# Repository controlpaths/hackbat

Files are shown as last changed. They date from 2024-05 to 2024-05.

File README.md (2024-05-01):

# Hackbat

HackBat is an open-source device designed for hackers and makers to experiment with different pen-testing techniques. The device is based on the Raspberry Pi RP2040 microcontroller and has an RF transceiver, NFC, WIFI, OLED display...

## RP2040

The Raspberry Pi [RP2040](https://www.raspberrypi.com/products/rp2040/specifications/) is the brain of the HackBat. The main features of this MCU are:

- Dual-core Arm Cortex-M0+ processor, flexible clock running up to 133 MHz 264kB on-chip SRAM
- 2 × UART 
- 2 × SPI controllers
- 2 × I2C controllers
- 16 × PWM channels
- 1 × USB 1.1 controller and PHY, with host and device support
- 8 × Programmable I/O (PIO) state machines for custom peripheral support
- Operating temperature -40°C to +85°C
- Drag-and-drop programming using mass storage over USB
- Low-power sleep and dormant modes
- Temperature sensor
- Accelerated integer and floating-point libraries on-chip

The RP2040 can be programmed using Arduino IDE, Python or C++.

## Display

The OLED display used in the HackBat is a 128x64 pixels, with the driver SH110X. The device also allows OLED with SSD1306, but notice that the VCC and GND pins are reversed, so you need to change the 0 ohm resistors of those pins.

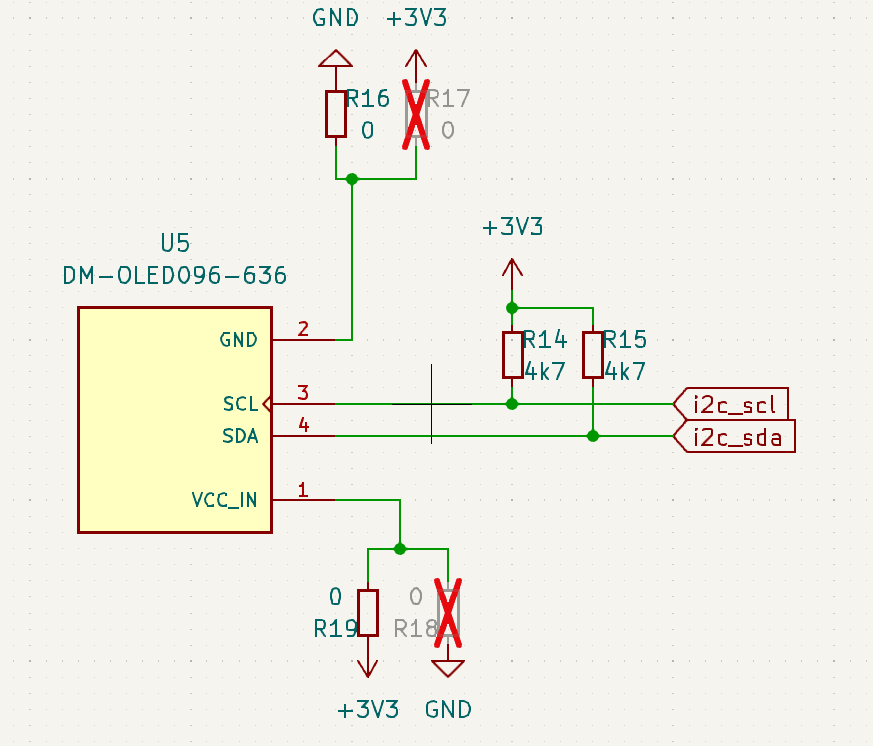
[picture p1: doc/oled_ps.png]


## RF

The Hackbat features a [CC1101](https://www.ti.com/product/CC1101) from Texas instruments. CC1101 is a low-cost sub-1 GHz transceiver designed for very low-power wireless applications. The circuit is mainly intended for the ISM (Industrial, cientific and Medical) and SRD (Short Range Device) frequency bands at 315, 433, 868, and 915 MHz, but can easily be programmed for operation at other frequencies in the 300-348 MHz, 387-464 MHz and 779-928 MHz bands

## WIFI

The hackBat features an ESP8266 module, the ESP-12F. This module allow either the HackBat to connect a WIFI network, or generate an access point to allow connections.

The ESP-12F modules can be programmed using the Arduino IDE and the UART conenction. In the HackBat, the ESP-12F is programmed through the RP2040 by using it as USB-UART bridge.

## NFC

HackBat has NFC communication at 13.56MHz. The IC in charge of this peripheral is the [PN532].

PN532 is a highly integrated transceiver module for contactless communication at 13.56 MHz based on the 80C51 microcontroller core supporting different card and reader/writer operating modes.

HackBat uses [this](https://es.aliexpress.com/item/1005006005040320.html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) integrated module with the PN532.

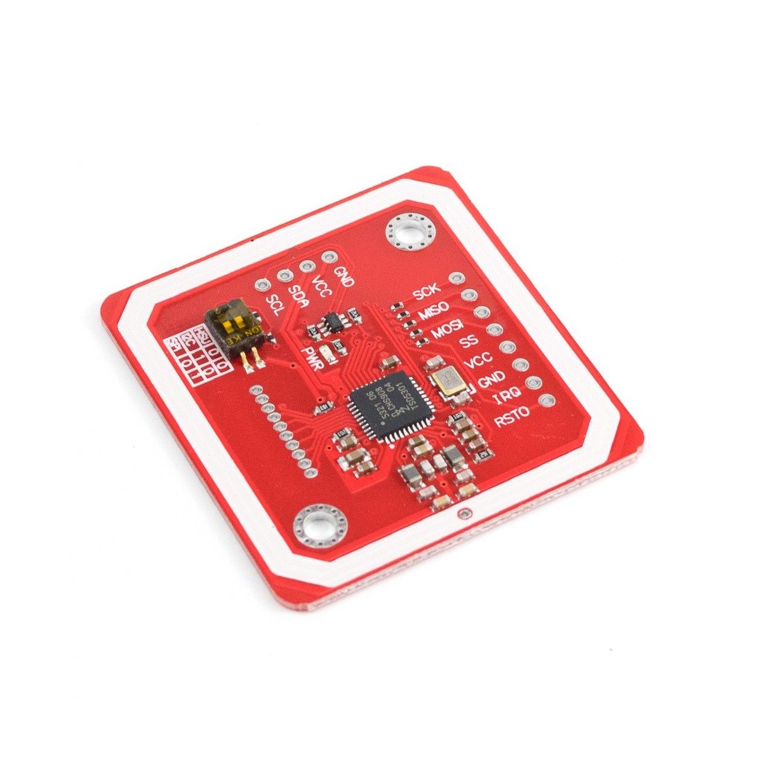
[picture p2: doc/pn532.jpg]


The communication with the RP2040 is I2C.

## Keyboard emulation

Since the RP2040 has USB host/Device, the HackBat can be used as a keyboard emulator using the Arduinoi `keyboard.h` library.

## Get Yours

The HackBat is open-source, so you can use the output files to manufacture your own in [JLCPCB](https://jlcpcb.com/?from=controlpath). You just need to compress the `output_files` directory, and upload it to [JLCPCB](https://jlcpcb.com/?from=controlpath). 

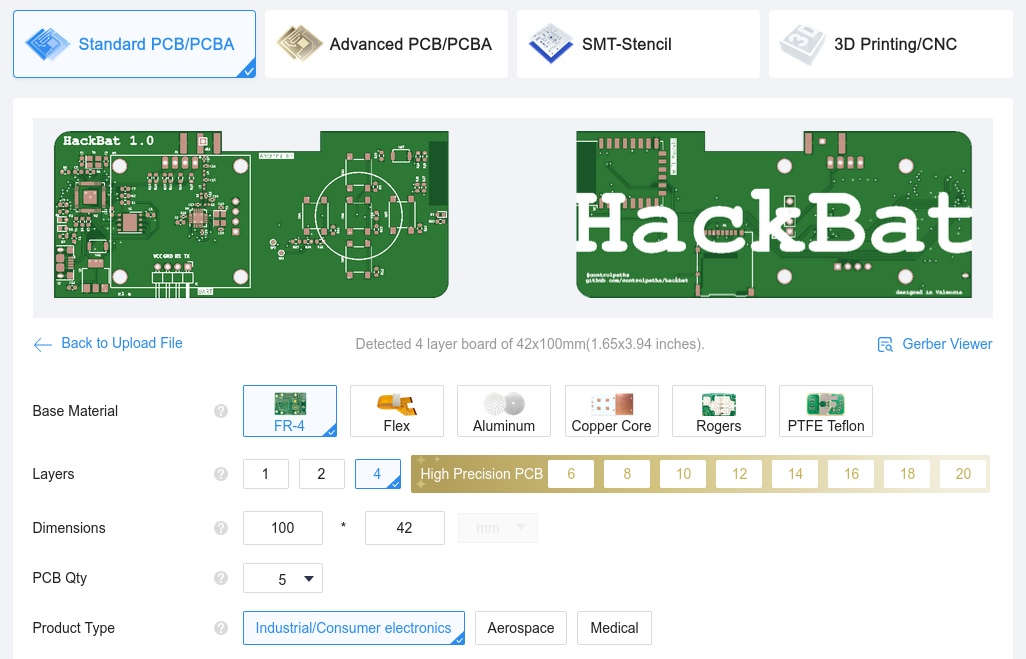
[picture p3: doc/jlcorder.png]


Remember to change the Surface Finish to **LeadFree HASL** to make your board ROHS compliant.

Then you have to add the PCB Assembly service and upload the [centroid](./kicad/hackbat/production_files/hackbat-all-pos.csv) file, and the [BOM](./kicad/hackbat/production_files/bom.csv). 

In a few days, you will receive your board at home.

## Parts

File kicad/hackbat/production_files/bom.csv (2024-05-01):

# | Reference | Qty | Value | Footprint | DNP | JLCPCB Part #
1 | AE1 | 1 | Antenna | TestPoint:TestPoint_THTPad_1.5x1.5mm_Drill0.7mm
2 | C1, C5, C7, C11 | 4 | 1u | Capacitor_SMD:C_0603_1608Metric
3 | C2, C3 | 2 | 15p | Capacitor_SMD:C_0603_1608Metric
4 | C4, C6, C8, C9, C10, C12 | 6 | 100n | Capacitor_SMD:C_0603_1608Metric
5 | C13, C21 | 2 | 3.9p | Capacitor_SMD:C_0402_1005Metric
6 | C14, C17 | 2 | 220p | Capacitor_SMD:C_0402_1005Metric
7 | C15 | 1 | 8.2p | Capacitor_SMD:C_0402_1005Metric
8 | C16 | 1 | 5.6p | Capacitor_SMD:C_0402_1005Metric
9 | C18 | 1 | 100n | Capacitor_SMD:C_0402_1005Metric
10 | C19, C20 | 2 | 27p | Capacitor_SMD:C_0402_1005Metric
11 | D1, D2, D3 | 3 | LED | LED_SMD:LED_0603_1608Metric |  | C19189746
13 | J2 | 1 | USB_B_Micro | Connector_USB:USB_Micro-B_Amphenol_10118193-0001LF_Horizontal |  | C132562
15 | J4 | 1 | Micro_SD_Card_Det_Hirose_DM3AT | Connector_Card:microSD_HC_Hirose_DM3AT-SF-PEJM5 |  | C114218
16 | J5 | 1 | Conn_01x04_Pin | Connector_PinHeader_2.54mm:PinHeader_1x04_P2.54mm_Horizontal
17 | L1, L2 | 2 | 27nH | Inductor_SMD:L_0402_1005Metric
18 | L3 | 1 | 22n | Inductor_SMD:L_0402_1005Metric
19 | L4 | 1 | 27n | Inductor_SMD:L_0402_1005Metric
20 | R1, R6 | 2 | 1k | Resistor_SMD:R_0603_1608Metric
21 | R2, R5 | 2 | 10k | Resistor_SMD:R_0603_1608Metric
22 | R3, R4 | 2 | 27 | Resistor_SMD:R_0603_1608Metric
23 | R7, R8, R9, R10, R11, R12, R13, R14, R15, R20, R22, R27, R28, R29 | 14 | 4k7 | Resistor_SMD:R_0603_1608Metric
24 | R16, R19, R23, R24, R25, R26 | 6 | 0 | Resistor_SMD:R_0603_1608Metric
26 | R21 | 1 | 56k | Resistor_SMD:R_0402_1005Metric
27 | SW1, SW7 | 2 | SW_Push | Button_Switch_SMD:SW_Push_SPST_NO_Alps_SKRK |  | C115357
28 | SW2, SW3, SW4, SW5, SW6 | 5 | SW_Push | Button_Switch_SMD:SW_Push_1P1T_NO_6x6mm_H9.5mm |  | C455109
30 | U1 | 1 | W25Q32JVZP | Package_SON:WSON-8-1EP_6x5mm_P1.27mm_EP3.4x4.3mm |  | C2940197
31 | U2 | 1 | RP2040 | Package_DFN_QFN:QFN-56-1EP_7x7mm_P0.4mm_EP3.2x3.2mm |  | C2040
32 | U3 | 1 | AMS1117-3.3 | Package_TO_SOT_SMD:SOT-223-3_TabPin2
33 | U4 | 1 | ESP-12F | RF_Module:ESP-12E |  | C784365
35 | U6 | 1 | CC1101 | Package_DFN_QFN:QFN-20-1EP_4x4mm_P0.5mm_EP2.6x2.6mm_ThermalVias |  | C29953
36 | Y1 | 1 | 12MHz | Crystal:Crystal_SMD_3225-4Pin_3.2x2.5mm |  | C524716
37 | Y2 | 1 | 27MHz | Crystal:Crystal_SMD_3225-4Pin_3.2x2.5mm |  | C254353

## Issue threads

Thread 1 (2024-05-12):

More info?

RonRN18, 2024-05-12:
I saw a blurb about this project but having difficulty finding any more information about it. From this Github, I see how the board can be built but as of yet, I have not seen any software to use on the hardware. Is more information forthcoming, such as instructions for programming and pointers on what can be accomplished with it?

rdfry, 2024-05-14:
I am also interested in programming this.

controlpaths, 2024-05-14:
Hi, this project is a HW platform. The board can be programmed using the Arduino IDE. All the peripherals except the RF have an Arduino library available so you can use it. For the RF IC, you need to modify the library from LSatan (SMARTRC-CC1101-Driver-Lib), or download the library from the repository of Joel Serna Moreno, who has a fork of the library modified for the RP2040.

Thanks!

Closed 2024-05-16.

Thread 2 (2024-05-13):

Layout issue?

DarthMuppet54, 2024-05-13:
This is excellent, many thanks for your efforts here.

I raised an order with PCBWAY for some of these to be built, and they have reported this to me:

> After checking your file, we found that there is via on pad in picture showing, may I know whether we should fill with resin or not
> 1. Fill with resin, the cost of pcb will increase and it will be good for assembly
> 2.Without resin, when you solder SMD components on pad, then paster will be easy leak out from pad

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

 Can you advise please?

Thanks

controlpaths, 2024-05-14:
Hi, some PCB manufacturers ask you about vias on pads because it could be a mistake, but not in this case.

Closed 2024-05-16.

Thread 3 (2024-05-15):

Bom file error

ygaspoz, 2024-05-15:
Hi, when uploading the files for the parts JLCPCB gives me the following error:
Error

The below parts won't be assembled due to data missing.
U5,J1,R18,R17 designators don't exist in the BOM file.
AE1 designator don't exist in the CPL file.

What is the fix?

fabinhojcr, 2024-05-15:
Upload the hackbat.zip file and you will be successful.

ygaspoz, 2024-05-15:
> Upload the hackbat.zip file and you will be successful.

I tried doing that, but when it prompts me to upload that BOM and CPL files I still get the same error.

TenThousand1, 2024-05-15:
I am also getting the exact same error message.

shayfer, 2024-05-15:
Same error message as well. It does make sense though since the hackbat-all-pos.csv references those items and they are not in the bom.csv file and vice versa for the AE1.

ygaspoz, 2024-05-16:
OK so i am correct in assuming that the display, antenna and NFC module need to be bought separately?

controlpaths, 2024-05-16:
That is correct. For the antenna, you can solder the antena or an SMA connector to attach an external antenna.

shayfer, 2024-05-16:
@controlpaths but you can add the antenna, LCD, etc to the bom & centroid file and have them do it correct?

MemomiAlexCherkashin, 2024-05-17:
What is final price of this assembly?
I've got something like:
Charge Details
PCB Price $7.00
Via Covering: $0.00
Special Offer: $7.00
Standard PCBA Price $163.22
Setup Fee: $50.00
Stencil: $15.71
Panel: $0.00
Large Size: $0.00
Components(30 items): $37.98
Feeders Loading fee:  $36.46
SMT Assembly $2.86
Hand-soldering labor fee: $3.50
Manual Assembly  $0.38
PCB assembly fixture  $15.71
Packaging fee: $0.47
Special components fee: $0.15
**Total Price:
$170.22**
Which does not include LCD Antenna, case etc..
So based on https://www.xda-developers.com/raspberry-pi-hackbot/ :
"However, unlike the Flipper Zero, the Hackbat is both open-source and cheaper than its cousin's $169 price tag."
Why???

chaton78, 2024-05-17:
Not sure what is your setup.. .my setup fee is 8$ not 50 and I took economic PCBA... 73$

MemomiAlexCherkashin, 2024-05-17:
> Not sure what is your setup.. .my setup fee is 8$ not 50 and I took economic PCBA... 73$

I managed to achieve this value by skipping of replacement for capacitors (which could not be found in the stock by default):
4,"C13, C21",2,3.9p,Capacitor_SMD:C_0402_1005Metric,,
5,"C14, C17",2,220p,Capacitor_SMD:C_0402_1005Metric,,
6,C15,1,8.2p,Capacitor_SMD:C_0402_1005Metric,,
7,C16,1,5.6p,Capacitor_SMD:C_0402_1005Metric,,
8,C18,1,100n,Capacitor_SMD:C_0402_1005Metric,,
And use economic PCBA like you say, but it means that this capacitors and TF port / RF module need to be soldered later alongside with antenna and display

jradm87, 2024-05-20:
Hello, i have problem too on the boom file:

Error

The below parts won't be assembled due to data missing.
U5,J1,R18,R17 designators don't exist in the BOM file.
AE1 designator don't exist in the CPL file.

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

Zeddex, 2024-05-21:
I got the same error:
The below parts won't be assembled due to data missing.
U5,J1,R18,R17 designators don't exist in the BOM file.
AE1 designator don't exist in the CPL file.

Is there fixed files?

MeanGreen420, 2024-05-23:
Ill try to help some,

When you get the Following error

**The below parts won't be assembled due to data missing.
U5,J1,R18,R17 designators don't exist in the BOM file.
AE1 designator don't exist in the CPL file.**

its because components are not intended to be installed by JLCPCB, you can install them yourself
U5 is the Display (DM-OLED096-636) as stated above
J1 is the 4 pins that connect the display that usually come with it if you order it from ebay or something.

R18 & R19 are not populated because they are used to change polarity for the display as explained in the documentation
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

AE1 is the antenna location, can be populated with a sma connector or a simple internal antenna, I haven't found a source for them yet.

I did also have to substitute many capacitors on my order because of supply shortages probably due to this project. I was able to find compatible substitutes for all of them though, this may be challenging if your not familiar with electronic components.

Hope this helps!

Closed 2024-05-29.

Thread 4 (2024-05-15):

RFID/IR support?

MonoTheProtogen, 2024-05-15:
I've basically heard about this today and immediately found this, and am really interested in this, now I noticed that the NFC module used in this project also supports RFID, would this also be the case with the device itself or would a separate integration need to be written into the firmware? I also wanted to ask, since I've looked through the schematics, would it be possible to use 2 of the 6 unoccupied pins on the RP2040 to add an infrared diode and infrared photoresistor to add infrared capabilities?

An additional idea of mine would be to route some power output pins, ground pins and the remaining 4 GPIO pins outside the board for a sort of expansion header for some stuff the end user might want to make, would these ideas be possible in theory?

controlpaths, 2024-05-16:
Hi, there is no official FW for the Hackbat, it is a HW platform for experiment with your own FW using the Arduino IDE or the RP2040 IDE so, if the NFC board supports the protocol you need you can use it without problem.

Regarding the IR, yes, you can, but both UART ports are already in use for the ESP programming and the external USB-UART converter. Maybe the best would be eliminate the external USB-UART connector and use it for the IR.

And of course, you can add an external port with the unused pins.

Thanks!

MonoTheProtogen, 2024-05-16:
noted, I'll see what I myself can do about adding IR to the board, having all of the schematics provided, plus the KiCAD files will help, thanks!

Closed 2024-05-16.

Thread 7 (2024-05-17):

please add more keys

zapewne, 2024-05-17:
**Please add https://reticulum.network/ directly. Only this functionality is good idea to but this device. (or meshtastic network)**

- Please add more keys, 16 is ok similar esphone or notkia
- I need socket for antenas. Sometimes external antena is better way to use than embeded
- This device must have a internal power. Meybe ad stepup down from 1V to 5V? Any AA, AAA, 18650 etc will work.

fachinformatiker, 2024-05-20:
You can find the schematics, PCB, etc in this Repo.
Download it and add the changes yourself, then upload the results :)
Well thank you

controlpaths, 2024-05-22:
Correct, the idea is that anybody could add their improvements and share it. In any case, more keys? Seems that you want a phone, that is not the goal of this project. Anyway, you can add all the keys you need and share it. Thanks!

fab1an2, 2024-05-22:
It seems that if you want to enter some data, number and ip mask, or password then you will appreciate more keys.

In my opinion, it is very necessary right away in the first model.

And if you want to write a message? Who knows what people will use it for?

Closed 2024-05-22.

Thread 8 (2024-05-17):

RP2040 Board

thealidev, 2024-05-17:
Is the `RP2040` board is respary pi pico ?

rdfry, 2024-05-17:
It's the same MCU sans the bd

thealidev, 2024-05-17:
What do you mean?

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

rdfry, 2024-05-20:
This board just uses the 2040 mcu and has nothing to do with the pico

thealidev, 2024-05-20:
Where can i buy it
Don't say Amazon or eBay
I live in Pakistan
So i need it here for cheap

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

rdfry, 2024-05-20:
Try Ada Fruit

thealidev, 2024-05-20:
Link ...

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

rdfry, 2024-05-22:
Try cytron.com

Zaidx1, 2024-05-23:
cytron.com is not opening

rdfry, 2024-05-23:
Sorry it's cytron.io

Closed 2024-05-27.

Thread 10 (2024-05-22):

About library

Yadavbhargav64, 2024-05-22:
Which are library and code should install please give us detail instructions

rdfry, 2024-05-22:
He is only providing this as a hardware project. It is up to the makers to code it

Zaidx1, 2024-05-23:
So there is no code available

rdfry, 2024-05-23:
No

MeanGreen420, 2024-05-23:
if you look in the Closed Issues section here [https://github.com/controlpaths/hackbat/issues/1](url) you will find this

Hi, this project is a HW platform. The board can be programmed using the Arduino IDE. All the peripherals except the RF have an Arduino library available so you can use it. For the RF IC, you need to modify the library from LSatan (SMARTRC-CC1101-Driver-Lib), or download the library from the repository of Joel Serna Moreno, who has a fork of the library modified for the RP2040.

Closed 2024-05-27.

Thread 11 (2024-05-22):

Is hackbat open source?

abetusk, 2024-05-22:
From the current snapshot of the [README](https://github.com/controlpaths/hackbat/commit/bff41e948238f449d6270b0ac630243a59458e9c):

> HackBat is an open-source device designed for hackers and makers to experiment with different pen-testing techniques.

As of this writing, this project is, as far as I can tell, "closed source" (at least here in the US) since there is no indication about what license is that the project falls under. I don't see a LICENSE file for the project nor do I see license information on any of the digital artifacts. If I've missed these, my apologies.

"Open Source" has a generally accepted meaning of being able to use the digital artifacts for commercial purposes. The OSI and Wikipedia's entry on [open-source licensing](https://en.wikipedia.org/wiki/Open-source_license) both articulate that commercial re-use is a (generally accepted) requirement of an "open source" license. The Open Source Hardware Association (OSHWA) has a [defintion](https://www.oshwa.org/definition/) of Open Source Hardware. As clarification, OSHWA provides a list of [best practices](https://www.oshwa.org/sharing-best-practices/) and [FAQ](https://www.oshwa.org/faq).

Was the intent to make this project libre/free/open source?

If so, could you indicate the license, either by providing a LICENSE file with the appropriate license or by putting a license information in the relevant digital artifacts (preferably both)?

If not, it might be good to clarify what the restrictions are to avoid confusion.

Closed 2024-07-24.

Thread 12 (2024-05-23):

Can i make it with pi pico w board

Zaidx1, 2024-05-23:
Is it possible to hook up the modules like RFID sensor CC1101 and oled display with raspberry piko w board and connect ESP 32 as well with wires and program both board separately by using their USB port or we can only use PCB version of this flipper zero

controlpaths, 2024-05-27:
Hi, yes, you can buy the boards separately and it will work. This project just build in one board different development boards. You can find more info on the hackster project.

Zaidx1, 2024-06-02:
Ok. But where is the code file

controlpaths, 2024-07-24:
Tou can use Arduino libraries for all the components of the board. I do not provide the code because I just tested all the peripherals but I don't have an application code

Closed 2024-07-24.

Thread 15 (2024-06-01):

Display Size

MeanGreen420, 2024-06-01:
I just got my batch of boards and noticed the .96" Display doesn't fit the outline and pins, it looks like a 1.3" would fit better.  Anyone else notice this?

bfpa40, 2024-06-01:
Im glad I just read this as I am almost prepared to order from JLCPCB. If Im reading the main post correctly the schematics reflect the DM-OLED096-636 for the .96" Display then pin 1 = Ground, Pin 2 = VCC, if you choose to use the SSD1306 then pin 1 = Ground and pin 2 = VCC. Correct?

rdfry, 2024-06-01:
yeah it would be nice to know what the overall dimentions of the lcd bd is. the profile is 36mm x 34mm

bfpa40, 2024-06-01:
Ive now looked at both displays and they both say .96" must be the pin layout is different i assume?

rdfry, 2024-06-01:
except the screen shown is almost the size of the bd profile which is 1.5 " wide x  1.325 " tall

bfpa40, 2024-06-01:
Here is what I am showing:
For the SSD1306
(26.70mm x 19.26mm x 1.85mm) or (1.051181”  x  0.7582677”  x  0.07283465”)

For the DM-OLED096-636
(26mm x 26mm x 2.7mm) or  (1.023622”  x  1.023622”  x 0.1062992”)

rdfry, 2024-06-01:
that just dosent seem to be big enough. i posted a question in the ada fruit forum. i love ada fruit but im not paying what they want for a screen. Ali Express if i can find the screen that fits

bfpa40, 2024-06-01:
I understand a little better now you want a larger screen... Ive got my order in the cart on JLCPCB but im at a halt now because there isnt a baseline firmware/software image to flash to it as of yet and I havent had the greatest support with folks online trying to get info to get new devices up and running..so Im at a standstill

rdfry, 2024-06-01:
i know i'm just going off the picture of the bd  that has the screen on it. i have the bds from jlcpcb. and the bd with the screen has to be 1.5" X 1.325" overall.  i have a .96 Screen and the bd is way to small. it is just frustrating that the vendors dont provide the bd dimentions  along with the screen size

MeanGreen420, 2024-06-01:
my .96" displays are about 1 1/16th  so im guessing the 1.3 display will be close to 1.5, also all the 1.5" displays I have seen have the connector on the side not the top.

rdfry, 2024-06-01:
my .96" display bd measures 1" square

MeanGreen420, 2024-06-02:
the outline of the display on the board only measures 1 3/8" also so its not 1 1/2"

rdfry, 2024-06-02:
your right i cant read a ruler. 1 3/8 x 1 5/16

rdfry, 2024-06-08:
Received a 1.3 display the mounting holes are slightly off but the board fits the outline

MeanGreen420, 2024-06-09:
same here, just got mine today. just to be clear since I didn't state it very clear, the 1" display connection pins do match up, its the mounting holes and outline that didn't match, the 1.3" display is much better, I was able to use m2.5 screws and nuts to secure mine to the board also.

bfpa40, 2024-06-09:
So which display is the 1.3" display do you have a P/N  to insure i get the correct one?

MeanGreen420, 2024-06-09:
Product Introduction:
1.Size:1.3 inch
2.Resolution:128*64
3.Controlling Chip:SSH1106
4.Display Area:29.42*14.7mm
5.Driving Voltage:3.3-5V
6.Operating Temperature:-40~70 celsius
7.Interface Type:IIC
8.Light Color: white

[https://www.ebay.com/itm/186114101614](url)

rdfry, 2024-06-09:
Just found this amazing item on AliExpress. Check it out!
$2.87 | 1.3 Inch 1.3" White OLED LCD 4PIN Display Module IIC I2C Interface 128x64 for Arduino
https://a.aliexpress.com/_msY2vIm

bfpa40, 2024-06-09:
If anyone in here has ordered there boards where did you order them from? I have 5 in the cart now at JLCPCB total cost for all 5 making and populating these boards there is $176.77  thats  $35.34 each

rdfry, 2024-06-09:
I just had jlcpcp make the boards. Cost about 15 dollars. I am doing my own smt. You really only need the components on one of the boards unless you want 5 complete boards.

bfpa40, 2024-06-09:
I want 5 complete boards so I can have 2 and sell the other 3 to recoup some $$

MeanGreen420, 2024-06-09:
I had them only populate the front side of the board, its much more expensive to have them do both, the esp12 is pretty easy to solder on, the sd card holder can be done with a iron if your careful, I used my hot air rework station.  Also if your trying to recoup some money have them make 10, an additional 5 board is a fraction of the cost, I only had to pay like $25 more dollars to make 5 more.

bfpa40, 2024-06-15:
I Received my OLED displays in the 1.3" and I tried them using a RaspberryPi Pico and while I thought they were of the ssd1306 flavor driver I couldnt get them working until i used the sh1106 version driver in the pico. Just wanted to add this here in case anyone else was having issues

Closed 2024-07-24.

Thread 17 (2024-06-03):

BOM / CPL Error @ JLCPCB

boopboopboopers, 2024-06-03:
The following are given when uploading BOM and CPL files.

"Error

The below parts won't be assembled due to data missing.
U5,J1,R18,R17 designators don't exist in the BOM file.
AE1 designator don't exist in the CPL file."

SanchosPoncho, 2024-06-06:
Please refer to https://github.com/controlpaths/hackbat/issues/3

These are materials that are provide by installing the screen, NFC, and radio antenna to the board that have to completed after the fact.

boopboopboopers, 2024-06-07:
Well, I feel like a dufus. Makes total sense. Got ahead of myself. Thanks for the response.

bfpa40, 2024-06-15:
Whats the voltage value for Capacitor C18? Anyone know?

controlpaths, 2024-07-24:
6.3V is enough for any capacitor.

Closed 2024-07-24.

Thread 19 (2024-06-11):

Plastic mounting hardware for LED

bfpa40, 2024-06-11:
Any suggestions on plastic hardware for mounting the LED and the NFC Board? Size Dimensions?

rdfry, 2024-06-15:
Plastic standoffs

bfpa40, 2024-06-15:
iN THE PICTURES THEY LOOK LIKE SCREWS AND NUTS..but what sizes?

controlpaths, 2024-06-19:
They are M3 screws.

Closed 2024-07-24.

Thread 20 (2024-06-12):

Jlcpcb question on my order - need help

bfpa40, 2024-06-12:
This is what they just emailed me:
Hello,
Sorry to bother you, but we'd like to confirm with you an issue found during review of your PCB order before proceeding.

As shown below,there are many files ,may we know if we can use output_files folder for PCB production ?

Your early reply will be highly appreciated, thank you so much!、

Here is a link to the screengrab not sure how to respond to them?  https://imgur.com/8zUjxvb

VeganismTho, 2024-07-01:
I'm a noob, but from what I understand you sent them the entire list of files and not just the compressed "output files". So you can tell them yes to use the output file. I imagine your comment may have come before such advice was put into the readme. Be sure to upload the centroid and BOM file. Not that I know what the does or how to do it yet. My response is too late for you I imagine, but should anyone else stumble on this problem hopefully this helps.

Closed 2024-07-24.

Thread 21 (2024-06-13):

JLCPCB Has an issue with C18 not fitting footprint

bfpa40, 2024-06-13:
Here is what they sent me. What did other folks use successfully for C18?

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

bfpa40, 2024-06-13:
Evidently no one else had issues with this component not fitting the footprint using JLCPCB and if you did what did you substitute it with? I still need assistance with this please someone HELP !?!?!

MeanGreen420, 2024-06-21:
I used C424821

Fdelro, 2024-08-12:
I have a similar issue, when I upload the Geber files and in the next step the bom.csv and the hackbat-all-pos.csv I get an error message with the following: Error
The below parts won't be assembled due to data missing.
U5,J1,18,R17 designators don't exist in the BOM file.
AE1 designator don't exist in the CPL file.

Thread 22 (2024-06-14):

HELP Needed

bfpa40, 2024-06-14:
JLCPCB after ordering emailed me back and said the footprint of C18 wont fit the pads it looks to be way small in the picture they sent me. What is the value of that capicitor? I know its 100 nano farads but how many volts should it be rated  for??  Better yet does anyone have a reference on the JLCPCB Part# they ordered that worked? My order is on hold until i get this part corrected.
The Part they have which came from the BOM says its as follows:

6.3V 100nF X5R ±10% 01005 Multilayer Ceramic Capacitors MLCC - SMD/SMT ROHS

I see the problem is that the package is 01005 instead of 0402 but before i correct it I want to insure the values of the capacitor are correct (110n , 6.3V)  is that right Yes/No    and Thank You

controlpaths, 2024-07-24:
6.3 volts is enough for any capacitor. The board works at 3v3.

gh05t5, 2024-11-24:
Hello! I've uploaded the BOM and centroid files but when they get processed I get this error message:

**The below parts won't be assembled due to data missing.
U5,J1,R18,R17 designators don't exist in the BOM file.
AE1 designator don't exist in the CPL file.**

Please advise!

Thank you very much

WhaleWithCake, 2024-11-24:
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

See the issue resolved here: https://github.com/controlpaths/hackbat/issues/3

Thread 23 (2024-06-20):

RFID LF (125-150khz) support

Britaliope, 2024-06-20:
Hello,

I'm currently looking into this project, and it seems very intresting, however i'd like to have RFID LF support (especially for reading animal chips). I'm currently looking for suitable modules at a decent price that could be integrated on this, and if I manage to find something useful, i'll submit a PR with my modifications.

I am opening this issue to track progress. Also, if anyone already made some research about this i'd be happy to hear what you found and thoughts. @controlpaths , as you designed the board : do you have any insights or advice, or things to be careful about while choosing and modifying the kicad project ?

From what i saw, there are some GPIO pins available on the RP2040, so a UART module would be OK, but a I2C or SPI one would do too.

controlpaths, 2024-07-24:
Hi! The problem with low frequencies is that the antenna is bigger than for hundreds of MHz. I don't know modules for that frequency, but if you find it, it will need a PCB antenna.

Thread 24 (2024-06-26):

Received order from JLCPCB boards not trimmed

bfpa40, 2024-06-26:
Just received my order from JLCPCB but it seems as though they didnt remove the excess material from the top and the bottom of the boards.. Its "scored" on both sides if you would call it that but not removed. pretty firm still wont easily snap off ive never dealt with this before what is recommended? I could exert more force and use a vice OR use a box cutter to further score to remove.. what would folks recommend?
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

controlpaths, 2024-07-24:
Hi, you can break it with your hands. That part of pcb is needed for the PCB Assembly. All the assembled boards have it.

Closed 2024-07-24.

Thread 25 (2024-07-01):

Capacitor swaps c13-17 c21

VeganismTho, 2024-07-01:
on the site you can search for alternatives and it gives you 1 to 5 to pick from. Will just any of the alternatives they recc work as long as it doesn't have a question mark pointing out that the part is slightly off from the one requested? Right next to select a question mark when hovered over says:

"The part does not match the one(Comment: 3.9p Footprint: Capacitor_SMD:C_0402_1005Metric) provided in your BOM. Please confirm it."

These things are tiny, I'm hoping to avoid having to get a better solder set to put them in myself with the requested capacitors found elsewhere. Though might have to do that either way for the 5 parts or so we put on ourselves. Anyone have rec for solder set for working on these things?

I looked into a lil, seemed simple enough to swap parts out. Hopefully it works out. On to ordering the other parts.

rdfry, 2024-07-02:
Hot air gun

Closed 2024-07-05.

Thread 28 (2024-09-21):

Error when uploading the BOM and pos file

VisenDev, 2024-09-21:
The below parts won't be assembled due to data missing.
U5,J1,R18,R17 designators don't exist in the BOM file.
AE1 designator don't exist in the CPL file

VisenDev, 2024-09-21:
#3 duplicate

Closed 2024-09-21.

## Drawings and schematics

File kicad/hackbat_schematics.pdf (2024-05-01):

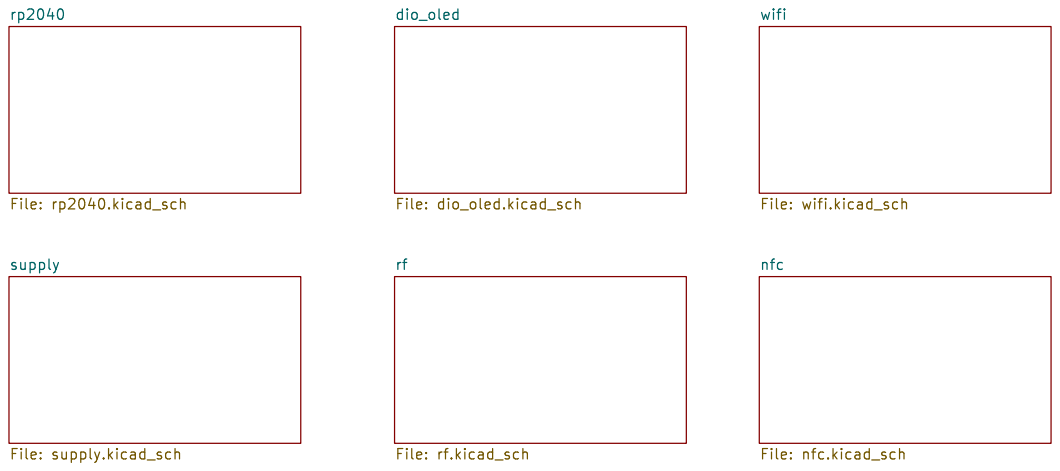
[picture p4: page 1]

nfc File: nfc.kicad_sch wifi File: wifi.kicad_sch

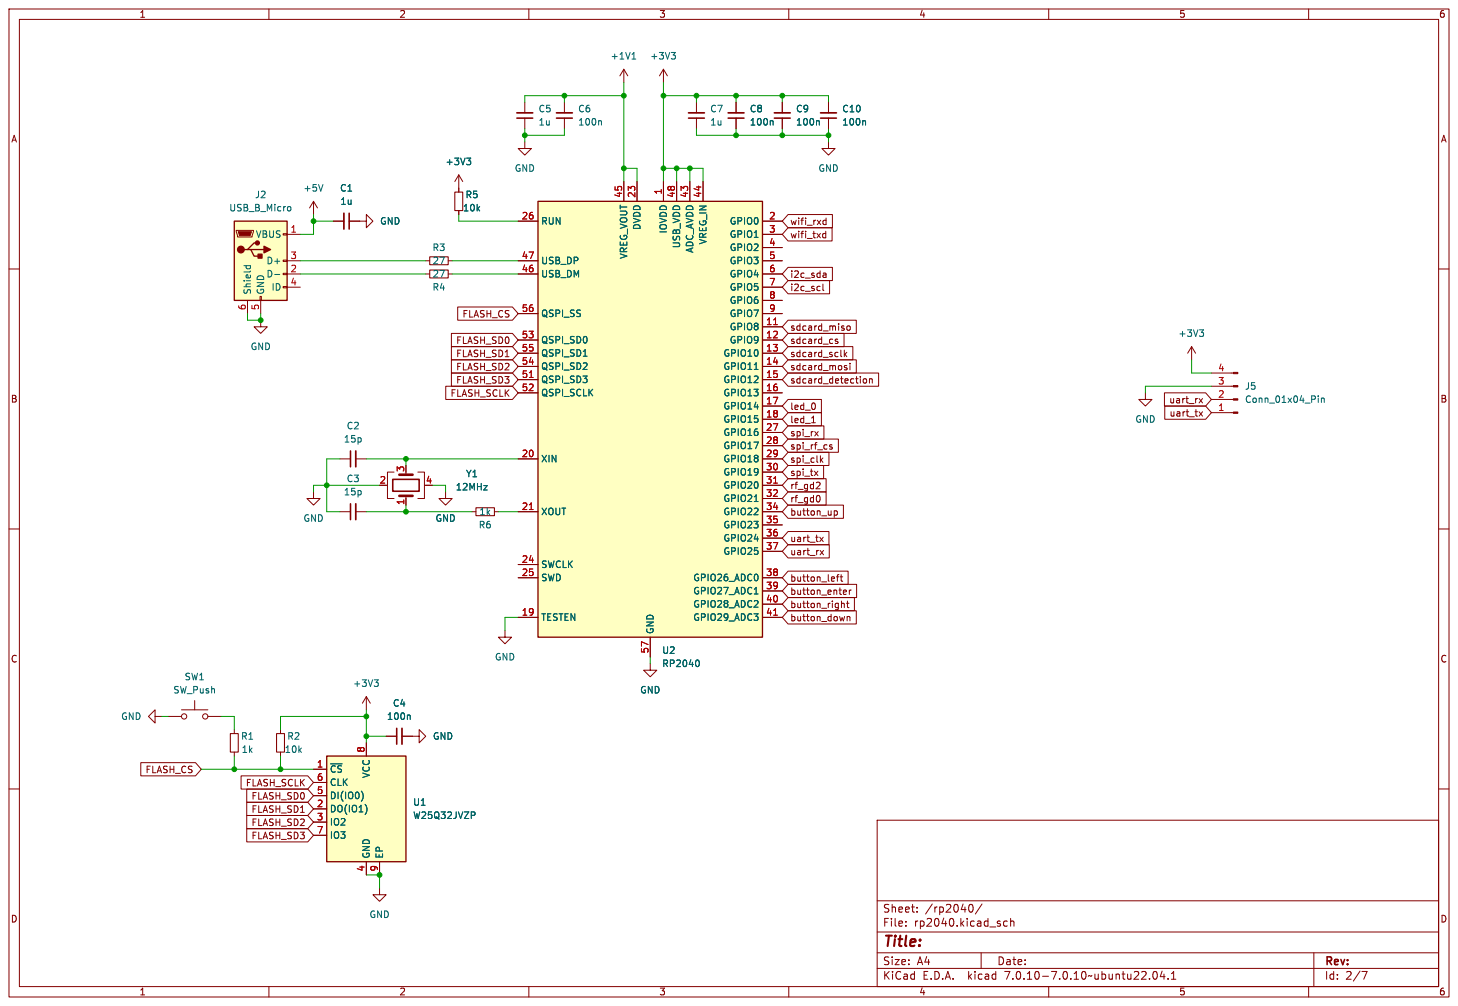
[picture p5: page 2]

1 GPIO8 11 GPIO9 12 GPIO10 13 GPIO11 14 GPIO12 15 GPIO13 16 GPIO14 17 GPIO15 18 TESTEN 19 GPIO0 2 XIN 20 XOUT 21 DVDD 23 SWCLK 24 SWD 25 RUN 26 GPIO16 27 GPIO17 28 GPIO18 29 GPIO1 3 GPIO19 30 GPIO20 31 GPIO21 32 GPIO22 34 GPIO23 35 GPIO24 36 GPIO25 37 GPIO26_ADC0 38 GPIO27_ADC1 39 GPIO2 4 GPIO28_ADC2 40 GPIO29_ADC3 41 ADC_AVDD 43 VREG_IN 44 VREG_VOUT 45 USB_DM 46 USB_DP 47 USB_VDD 48 GPIO3 5 QSPI_SD3 51 QSPI_SCLK 52 QSPI_SD0 53 QSPI_SD2 54 QSPI_SD1 55 QSPI_SS 56 GND 57 GPIO4 6 GPIO5 7 GPIO6 8 GPIO7 9 U2 RP2040 C4

1 GPIO8 11 GPIO9 12 GPIO10 13 GPIO11 14 GPIO12 15 GPIO13 16 GPIO14 17 GPIO15 18 TESTEN 19 GPIO0 2 XIN 20 XOUT 21 DVDD 23 SWCLK 24 SWD 25 RUN 26 GPIO16 27 GPIO17 28 GPIO18 29 GPIO1 3 GPIO19 30 GPIO20 31 GPIO21 32 GPIO22 34 GPIO23 35 GPIO24 36 GPIO25 37 GPIO26_ADC0 38 GPIO27_ADC1 39 GPIO2 4 GPIO28_ADC2 40 GPIO29_ADC3 41 ADC_AVDD 43 VREG_IN 44 VREG_VOUT 45 USB_DM 46 USB_DP 47 USB_VDD 48 GPIO3 5 QSPI_SD3 51 QSPI_SCLK 52 QSPI_SD0 53 QSPI_SD2 54 QSPI_SD1 55 QSPI_SS 56 GND 57 GPIO4 6 GPIO5 7 GPIO6 8 GPIO7 9 U1 W25Q32JVZP

Id: 2/7 Title: File: rp2040.kicad_sch Sheet: /rp2040/

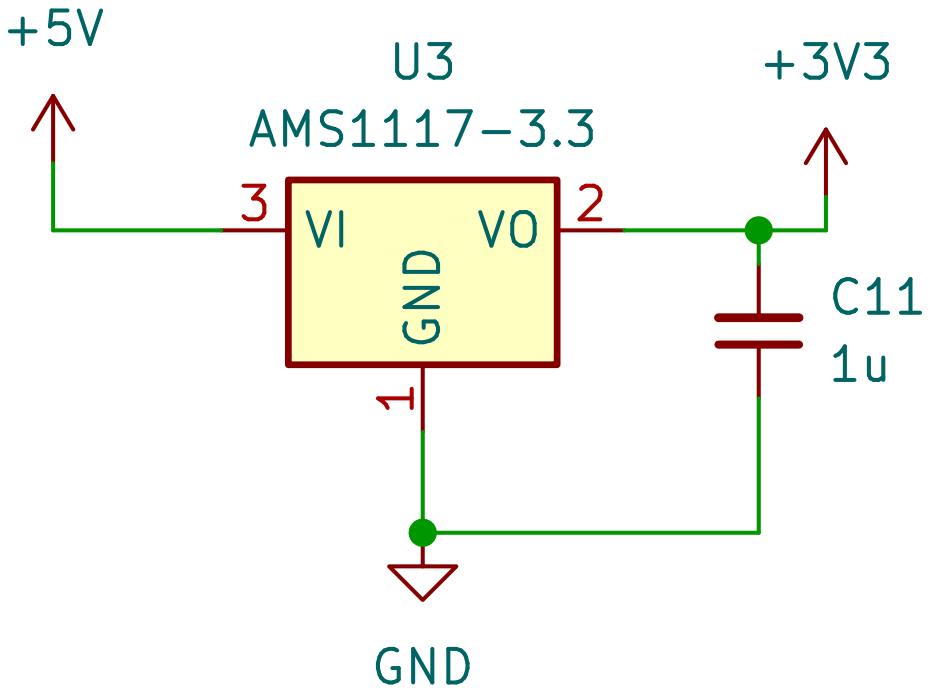
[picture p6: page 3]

Id: 3/7 Title: File: supply.kicad_sch Sheet: /supply/

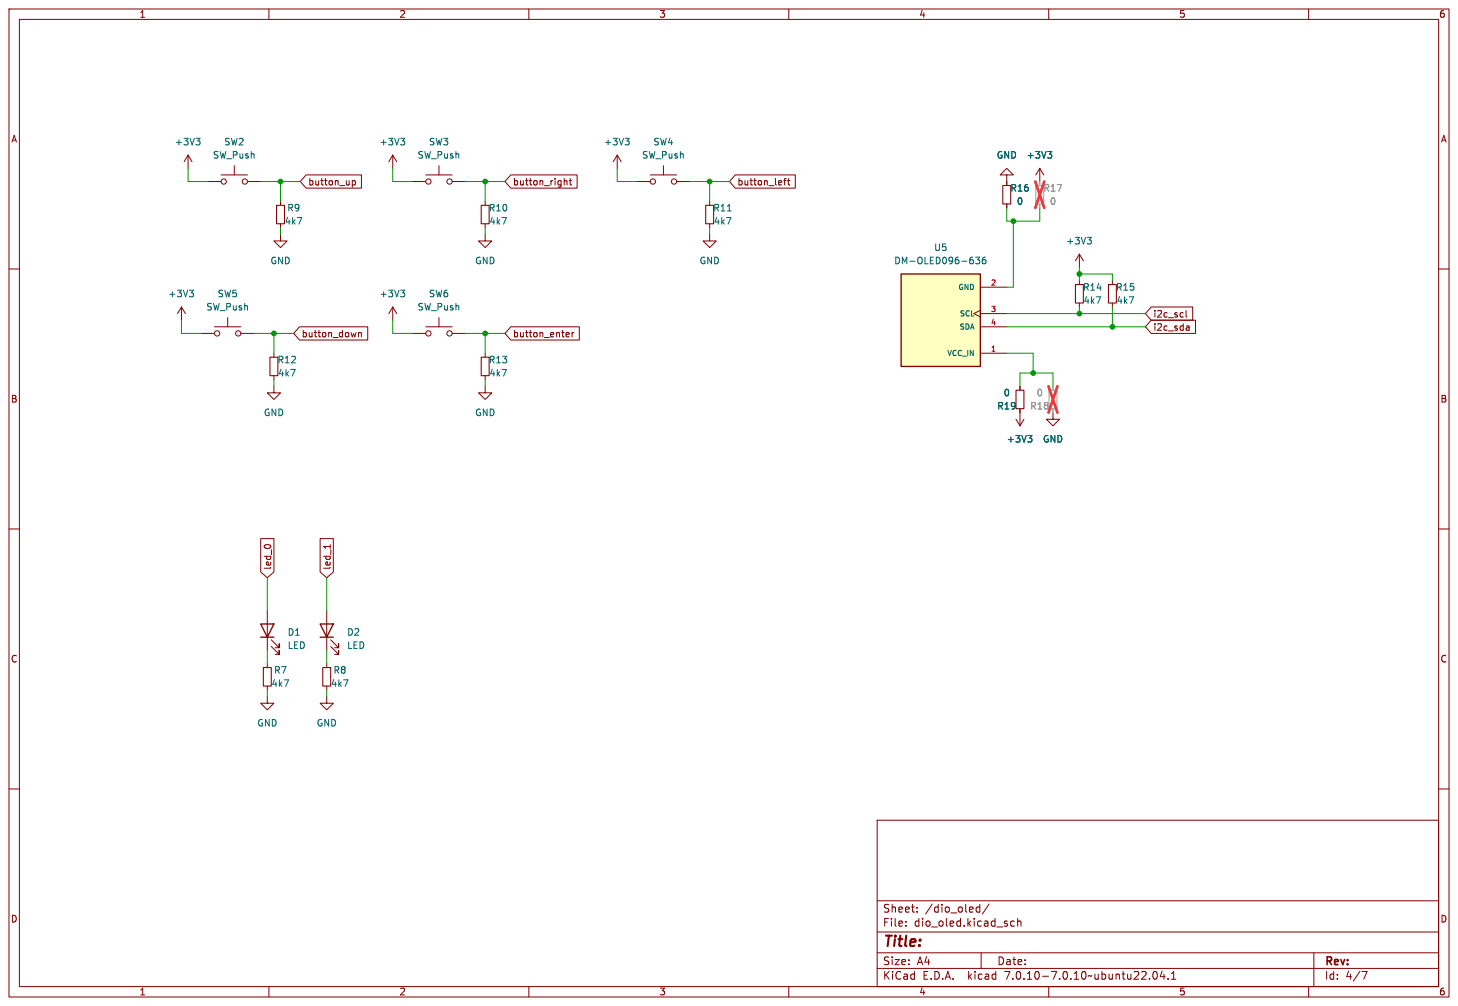
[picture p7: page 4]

Id: 4/7 Title: File: dio_oled.kicad_sch Sheet: /dio_oled/

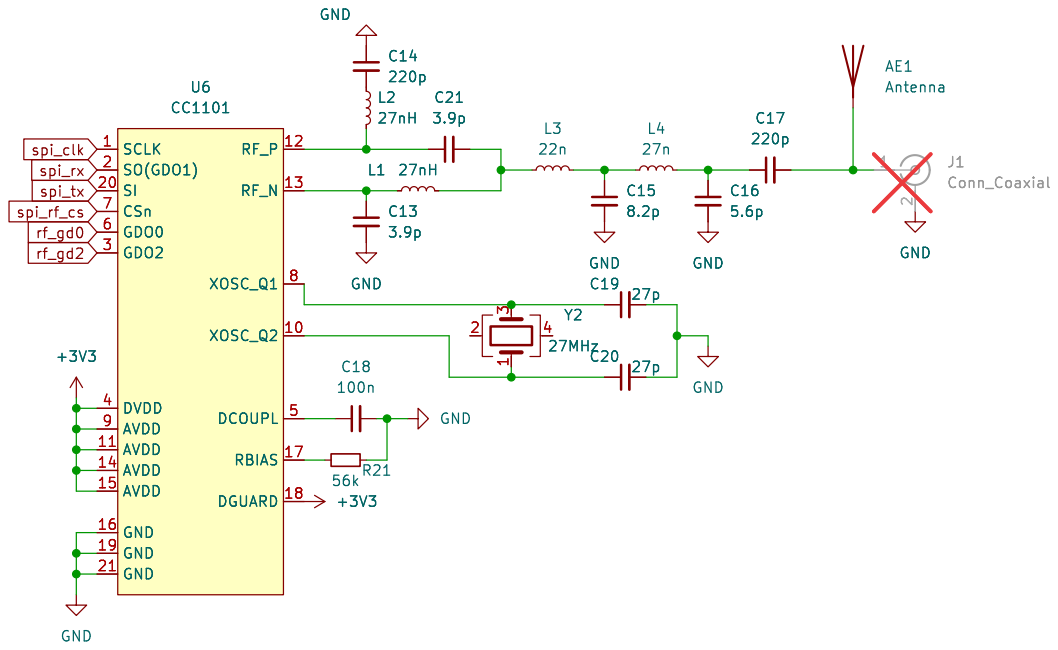
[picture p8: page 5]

Id: 5/7 Title: File: rf.kicad_sch Sheet: /rf/

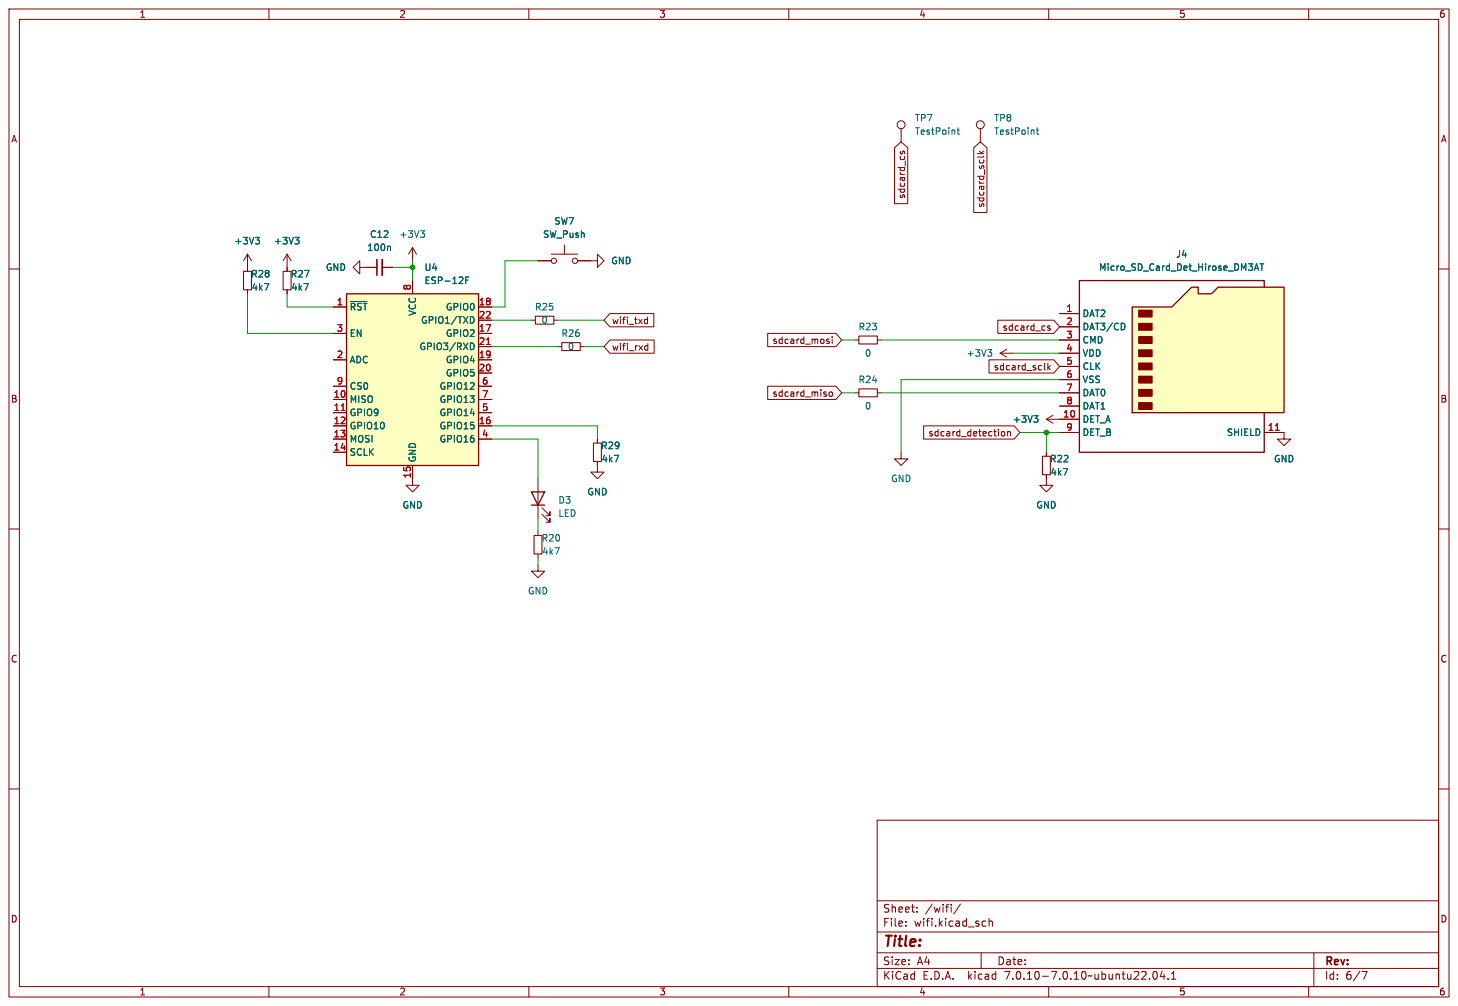
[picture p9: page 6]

Id: 6/7 Title: File: wifi.kicad_sch Sheet: /wifi/

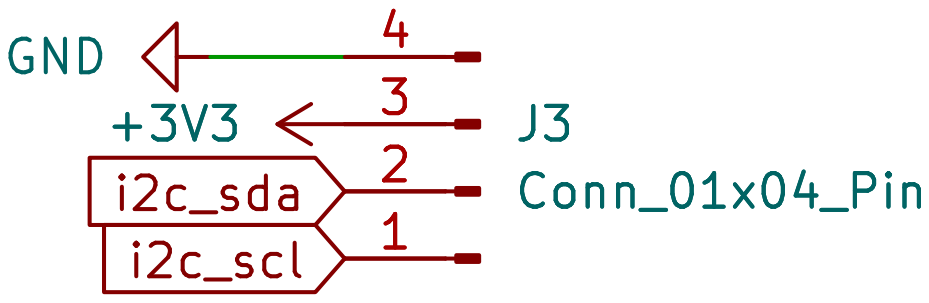
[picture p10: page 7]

Id: 7/7 Title: File: nfc.kicad_sch Sheet: /nfc/

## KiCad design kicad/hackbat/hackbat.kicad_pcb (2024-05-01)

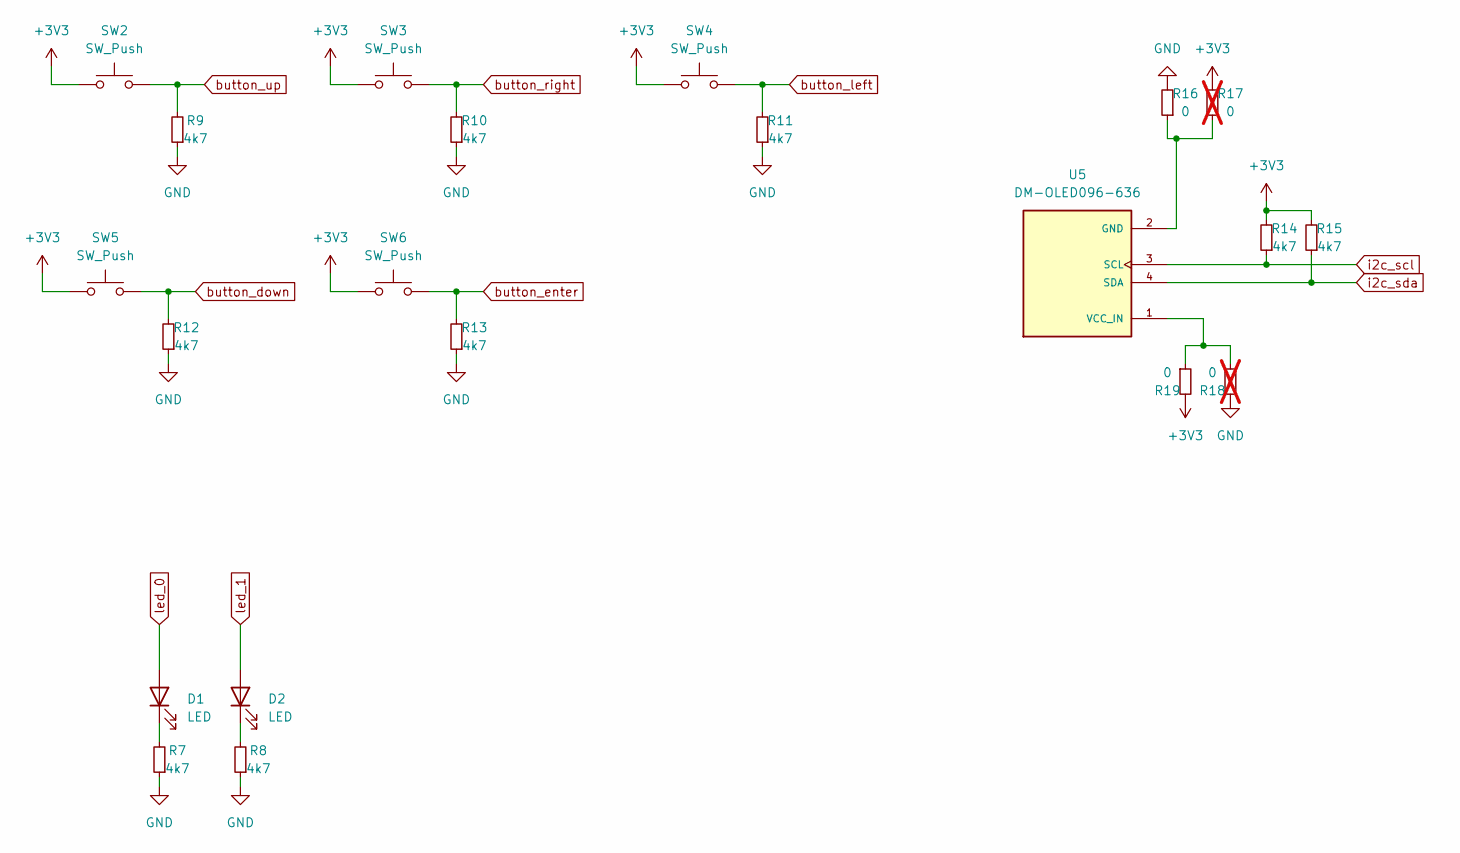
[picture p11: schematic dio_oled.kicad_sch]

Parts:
D1, D2: LED; LED_0603_1608Metric
R7, R8, R9, R10, R11, R12, R13, R14, R15: 4k7; R_0603_1608Metric
R16, R19: 0; R_0603_1608Metric
R17, R18: 0; R_0603_1608Metric; not fitted
SW2, SW3, SW4, SW5, SW6: SW_Push; SW_Push_1P1T_NO_6x6mm_H9.5mm; JLCPCB Part # C455109
U5: DM-OLED096-636; oled_1.3; PARTREV 2018-09-10

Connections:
+3V3: R14.2, R15.2, R17.2, R19.2, SW2.1, SW3.1, SW4.1, SW5.1, SW6.1; also elsewhere on the board
GND: R7.1, R8.1, R9.1, R10.1, R11.1, R12.1, R13.1, R16.2, R18.2; also elsewhere on the board
unnamed: D1.1 (K), R7.2
unnamed: D2.1 (K), R8.2
unnamed: R16.1, R17.1, U5.2 (GND)
unnamed: R18.1, R19.1, U5.1 (VCC_IN)
button_down: R12.2, SW5.2; also elsewhere on the board
button_enter: R13.2, SW6.2; also elsewhere on the board
button_left: R11.2, SW4.2; also elsewhere on the board
button_right: R10.2, SW3.2; also elsewhere on the board
button_up: R9.2, SW2.2; also elsewhere on the board
i2c_scl: R14.1, U5.3 (SCL); also elsewhere on the board
i2c_sda: R15.1, U5.4 (SDA); also elsewhere on the board
led_0: D1.2 (A); also elsewhere on the board
led_1: D2.2 (A); also elsewhere on the board

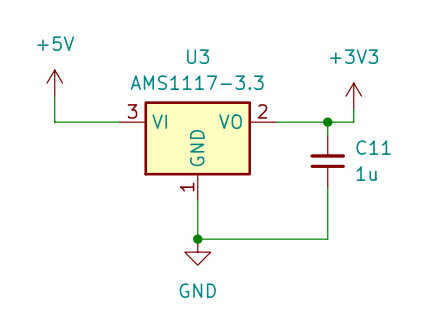
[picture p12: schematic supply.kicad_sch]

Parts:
C11: 1u; C_0603_1608Metric
U3: AMS1117-3.3; SOT-223-3_TabPin2

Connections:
+3V3: C11.2, U3.2 (VO); also elsewhere on the board
+5V: U3.3 (VI); also elsewhere on the board
GND: C11.1, U3.1 (GND); also elsewhere on the board

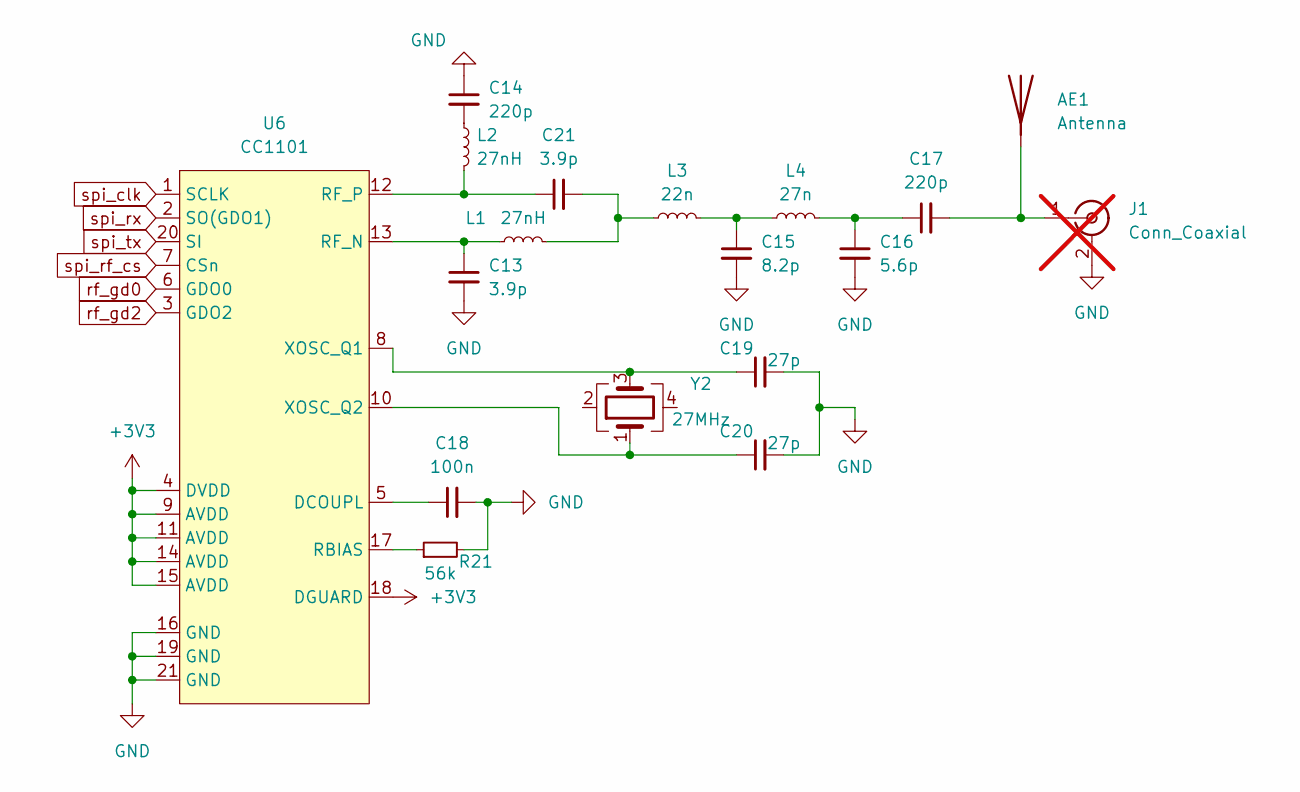
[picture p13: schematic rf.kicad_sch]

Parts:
AE1: Antenna; TestPoint_THTPad_1.5x1.5mm_Drill0.7mm
C13, C21: 3.9p; C_0402_1005Metric
C14, C17: 220p; C_0402_1005Metric
C15: 8.2p; C_0402_1005Metric
C16: 5.6p; C_0402_1005Metric
C18: 100n; C_0402_1005Metric
C19, C20: 27p; C_0402_1005Metric
J1: Conn_Coaxial; SMA_Amphenol_132289_EdgeMount; not fitted
L1, L2: 27nH; L_0402_1005Metric
L3: 22n; L_0402_1005Metric
L4: 27n; L_0402_1005Metric
R21: 56k; R_0402_1005Metric
U6: CC1101; QFN-20-1EP_4x4mm_P0.5mm_EP2.6x2.6mm_ThermalVias; JLCPCB Part # C29953
Y2: 27MHz; Crystal_SMD_3225-4Pin_3.2x2.5mm; JLCPCB Part # C254353

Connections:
+3V3: U6.4 (DVDD), U6.9 (AVDD), U6.11 (AVDD), U6.14 (AVDD), U6.15 (AVDD), U6.18 (DGUARD); also elsewhere on the board
GND: C13.2, C14.1, C15.2, C16.2, C18.2, C19.2, C20.2, J1.2 (Ext), R21.2, U6.16 (GND), U6.19 (GND), U6.21 (GND); also elsewhere on the board
unnamed: AE1.1 (A), C17.2, J1.1 (In)
unnamed: C14.2, L2.1
unnamed: C15.1, L3.2, L4.1
unnamed: C16.1, C17.1, L4.2
unnamed: C21.2, L1.2, L3.1
unnamed: C18.1, U6.5 (DCOUPL)
unnamed: R21.1, U6.17 (RBIAS)
unnamed: C13.1, L1.1, U6.13 (RF_N)
unnamed: C21.1, L2.2, U6.12 (RF_P)
unnamed: C19.1, U6.8 (XOSC_Q1), Y2.3
unnamed: C20.1, U6.10 (XOSC_Q2), Y2.1
rf_gd0: U6.6 (GDO0); also elsewhere on the board
rf_gd2: U6.3 (GDO2); also elsewhere on the board
spi_clk: U6.1 (SCLK); also elsewhere on the board
spi_rf_cs: U6.7 (CSn); also elsewhere on the board
spi_rx: U6.2 (SO(GDO1)); also elsewhere on the board
spi_tx: U6.20 (SI); also elsewhere on the board

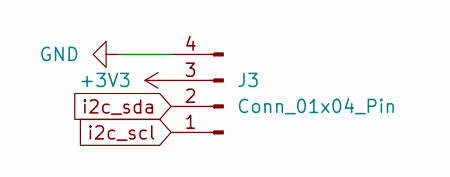
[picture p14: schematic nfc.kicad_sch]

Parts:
J3: Conn_01x04_Pin; PinHeader_1x04_P2.54mm_Vertical

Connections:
+3V3: J3.3; also elsewhere on the board
GND: J3.4; also elsewhere on the board
i2c_scl: J3.1; also elsewhere on the board
i2c_sda: J3.2; also elsewhere on the board

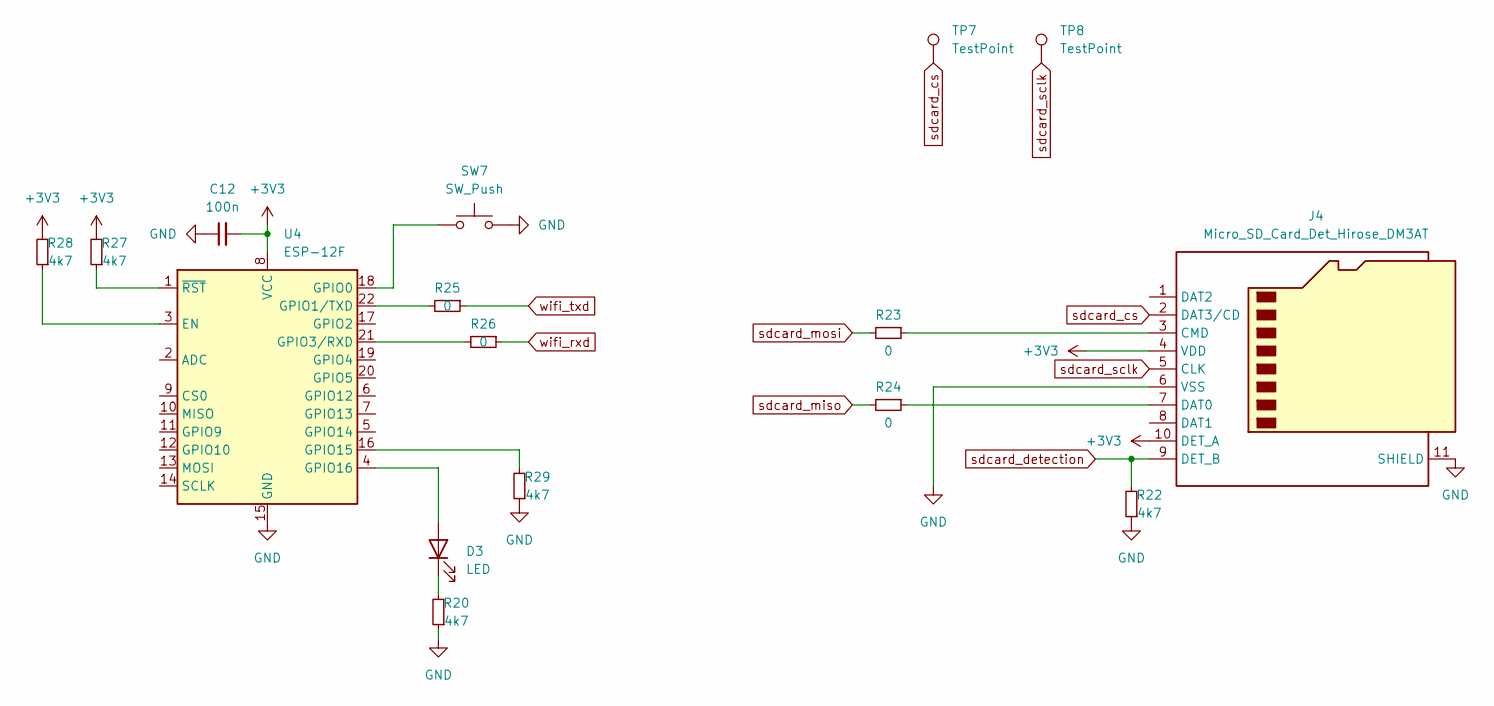
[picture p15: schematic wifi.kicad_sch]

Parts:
C12: 100n; C_0603_1608Metric
D3: LED; LED_0603_1608Metric
J4: Micro_SD_Card_Det_Hirose_DM3AT; microSD_HC_Hirose_DM3AT-SF-PEJM5; JLCPCB Part # C114218
R20, R22, R27, R28, R29: 4k7; R_0603_1608Metric
R23, R24, R25, R26: 0; R_0603_1608Metric
SW7: SW_Push; SW_Push_SPST_NO_Alps_SKRK; JLCPCB Part # C115357
TP7, TP8: TestPoint; TestPoint_Pad_D1.0mm
U4: ESP-12F; ESP-12E; JLCPCB Part # C784365

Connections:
+3V3: C12.2, J4.4 (VDD), J4.10 (DET_A), R27.2, R28.2, U4.8 (VCC); also elsewhere on the board
GND: C12.1, J4.6 (VSS), J4.11 (SHIELD), R20.1, R22.1, R29.1, SW7.2, U4.15 (GND); also elsewhere on the board
unnamed: D3.2 (A), U4.4 (GPIO16)
unnamed: D3.1 (K), R20.2
unnamed: J4.3 (CMD), R23.1
unnamed: J4.7 (DAT0), R24.1
unnamed: R28.1, U4.3 (EN)
unnamed: SW7.1, U4.18 (GPIO0)
unnamed: R25.2, U4.22 (GPIO1/TXD)
unnamed: R26.2, U4.21 (GPIO3/RXD)
unnamed: R29.2, U4.16 (GPIO15)
unnamed: R27.1, U4.1 (~RST)
sdcard_cs: J4.2 (DAT3/CD), TP7.1; also elsewhere on the board
sdcard_detection: J4.9 (DET_B), R22.2; also elsewhere on the board
sdcard_miso: R24.2; also elsewhere on the board
sdcard_mosi: R23.2; also elsewhere on the board
sdcard_sclk: J4.5 (CLK), TP8.1; also elsewhere on the board
wifi_rxd: R26.1; also elsewhere on the board
wifi_txd: R25.1; also elsewhere on the board

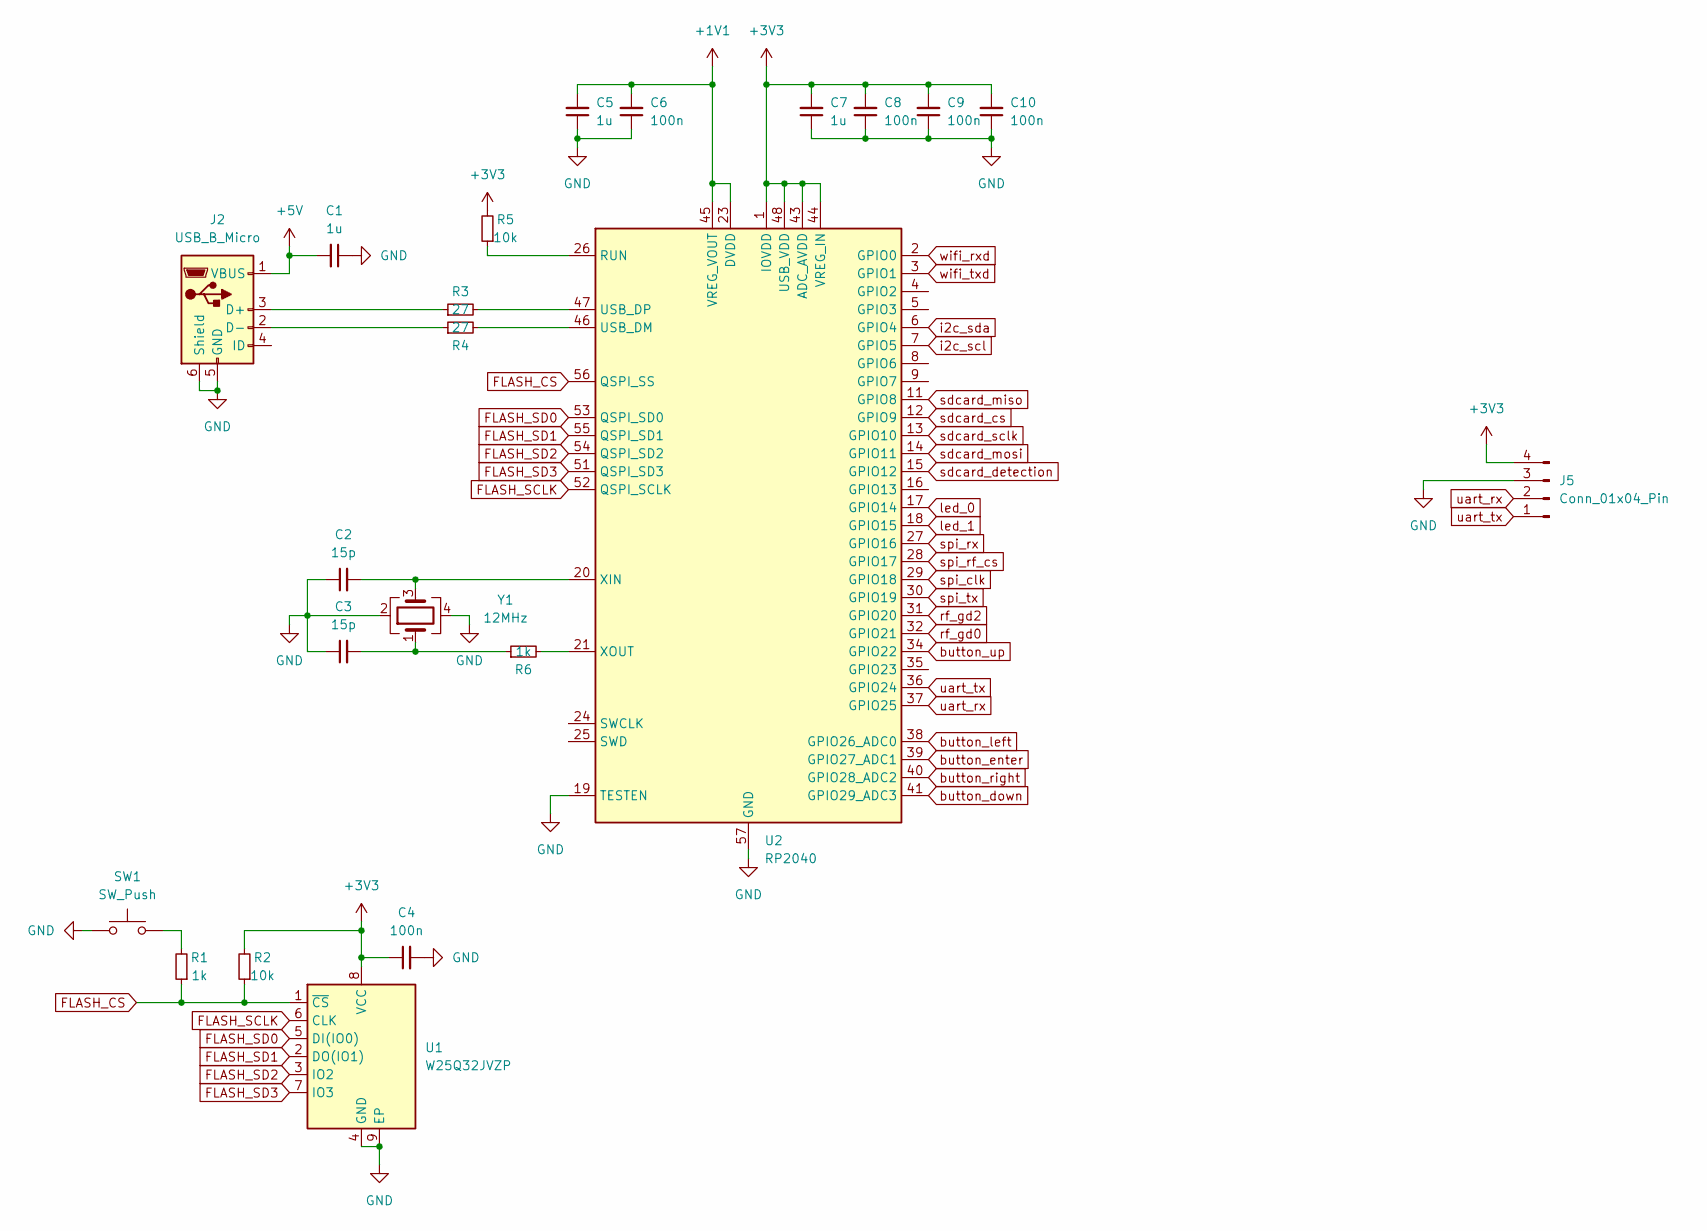
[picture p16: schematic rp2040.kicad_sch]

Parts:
C1, C5, C7: 1u; C_0603_1608Metric
C2, C3: 15p; C_0603_1608Metric
C4, C6, C8, C9, C10: 100n; C_0603_1608Metric
J2: USB_B_Micro; USB_Micro-B_Amphenol_10118193-0001LF_Horizontal; JLCPCB Part # C132562
J5: Conn_01x04_Pin; PinHeader_1x04_P2.54mm_Horizontal
R1, R6: 1k; R_0603_1608Metric
R2, R5: 10k; R_0603_1608Metric
R3, R4: 27; R_0603_1608Metric
SW1: SW_Push; SW_Push_SPST_NO_Alps_SKRK; JLCPCB Part # C115357
U1: W25Q32JVZP; WSON-8-1EP_6x5mm_P1.27mm_EP3.4x4.3mm; JLCPCB Part # C2940197
U2: RP2040; QFN-56-1EP_7x7mm_P0.4mm_EP3.2x3.2mm; JLCPCB Part # C2040
Y1: 12MHz; Crystal_SMD_3225-4Pin_3.2x2.5mm; JLCPCB Part # C524716

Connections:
+1V1: C5.2, C6.2, U2.23 (DVDD), U2.45 (VREG_VOUT), U2.50 (DVDD)
+3V3: C4.1, C7.2, C8.2, C9.2, C10.2, J5.4, R2.2, R5.2, U1.8 (VCC), U2.1 (IOVDD), U2.10 (IOVDD), U2.22 (IOVDD), U2.33 (IOVDD), U2.42 (IOVDD), U2.43 (ADC_AVDD), U2.44 (VREG_IN), U2.48 (USB_VDD), U2.49 (IOVDD); also elsewhere on the board
+5V: C1.2, J2.1 (VBUS); also elsewhere on the board
FLASH_CS: R1.1, R2.1, U1.1 (~CS), U2.56 (QSPI_SS)
FLASH_SCLK: U1.6 (CLK), U2.52 (QSPI_SCLK)
FLASH_SD0: U1.5 (DI(IO0)), U2.53 (QSPI_SD0)
FLASH_SD1: U1.2 (DO(IO1)), U2.55 (QSPI_SD1)
FLASH_SD2: U1.3 (IO2), U2.54 (QSPI_SD2)
FLASH_SD3: U1.7 (IO3), U2.51 (QSPI_SD3)
GND: C1.1, C2.1, C3.1, C4.2, C5.1, C6.1, C7.1, C8.1, C9.1, C10.1, J2.5 (GND), J2.6 (Shield), J5.3, SW1.1, U1.4 (GND), U1.9 (EP), U2.19 (TESTEN), U2.57 (GND), Y1.2, Y1.4; also elsewhere on the board
unnamed: C3.2, R6.1, Y1.1
unnamed: J2.3 (D+), R3.1
unnamed: J2.2 (D-), R4.1
unnamed: R1.2, SW1.2
unnamed: R5.1, U2.26 (RUN)
unnamed: R4.2, U2.46 (USB_DM)
unnamed: R3.2, U2.47 (USB_DP)
unnamed: C2.2, U2.20 (XIN), Y1.3
unnamed: R6.2, U2.21 (XOUT)
button_down: U2.41 (GPIO29_ADC3); also elsewhere on the board
button_enter: U2.39 (GPIO27_ADC1); also elsewhere on the board
button_left: U2.38 (GPIO26_ADC0); also elsewhere on the board
button_right: U2.40 (GPIO28_ADC2); also elsewhere on the board
button_up: U2.34 (GPIO22); also elsewhere on the board
i2c_scl: U2.7 (GPIO5); also elsewhere on the board
i2c_sda: U2.6 (GPIO4); also elsewhere on the board
led_0: U2.17 (GPIO14); also elsewhere on the board
led_1: U2.18 (GPIO15); also elsewhere on the board
rf_gd0: U2.32 (GPIO21); also elsewhere on the board
rf_gd2: U2.31 (GPIO20); also elsewhere on the board
sdcard_cs: U2.12 (GPIO9); also elsewhere on the board
sdcard_detection: U2.15 (GPIO12); also elsewhere on the board
sdcard_miso: U2.11 (GPIO8); also elsewhere on the board
sdcard_mosi: U2.14 (GPIO11); also elsewhere on the board
sdcard_sclk: U2.13 (GPIO10); also elsewhere on the board
spi_clk: U2.29 (GPIO18); also elsewhere on the board
spi_rf_cs: U2.28 (GPIO17); also elsewhere on the board
spi_rx: U2.27 (GPIO16); also elsewhere on the board
spi_tx: U2.30 (GPIO19); also elsewhere on the board
uart_rx: J5.2, U2.37 (GPIO25)
uart_tx: J5.1, U2.36 (GPIO24)
wifi_rxd: U2.2 (GPIO0); also elsewhere on the board
wifi_txd: U2.3 (GPIO1); also elsewhere on the board

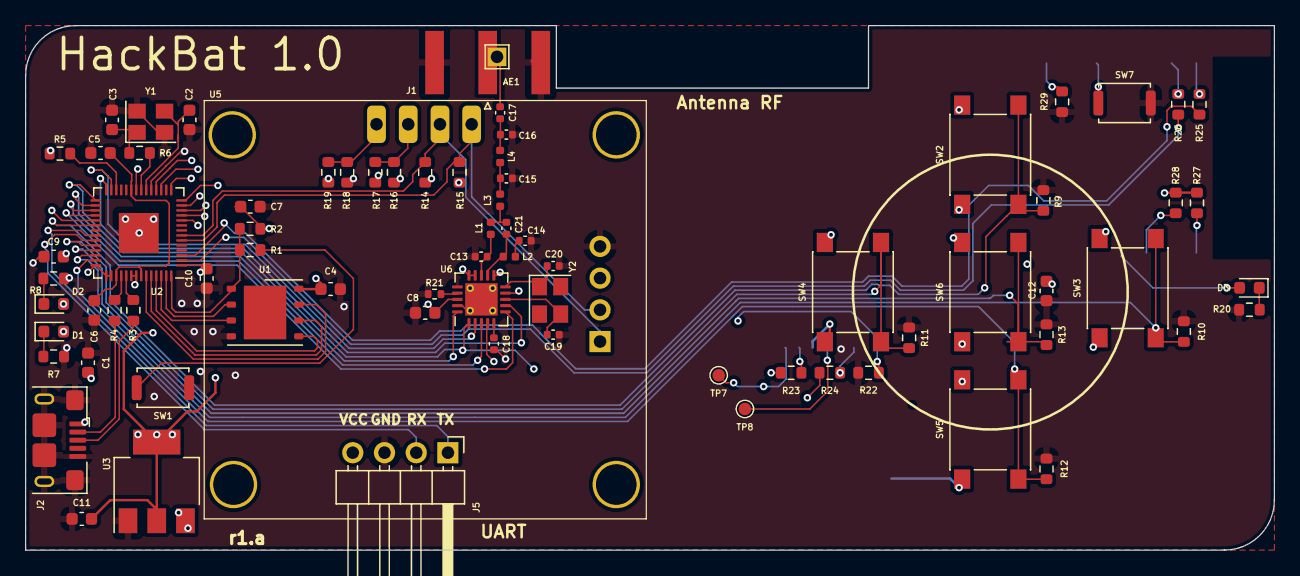
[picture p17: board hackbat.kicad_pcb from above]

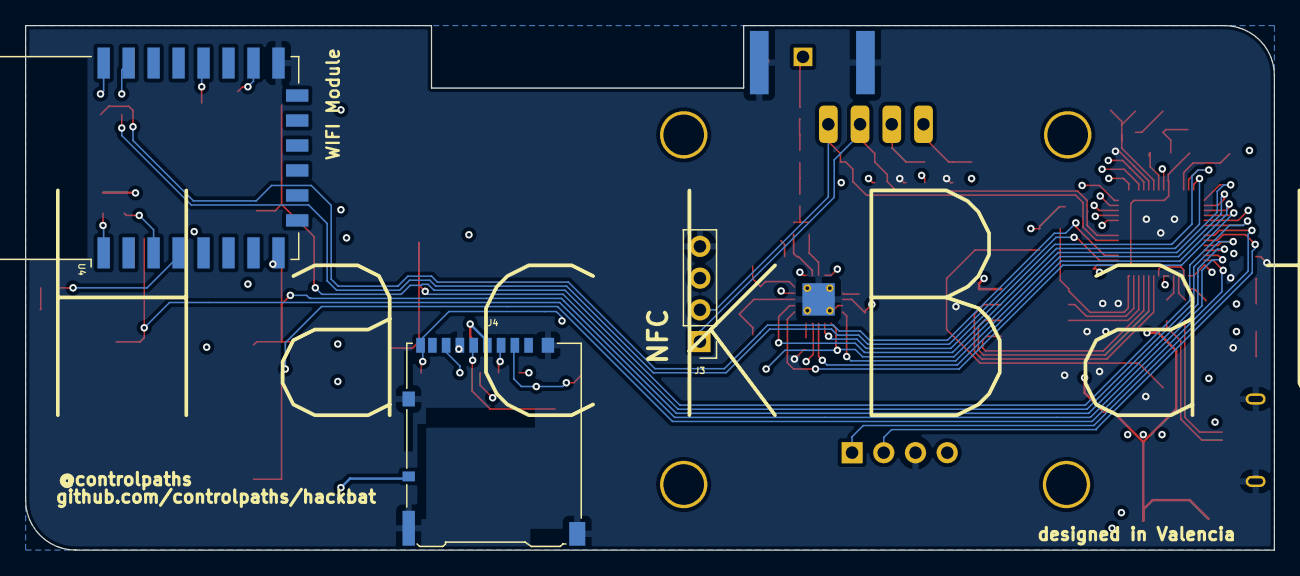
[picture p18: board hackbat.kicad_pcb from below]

Board: 4 copper layers, 100.0 x 42.0 mm, 80 parts (3 on the bottom side), 68 nets.
